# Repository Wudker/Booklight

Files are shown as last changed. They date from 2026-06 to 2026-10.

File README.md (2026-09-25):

# BookLight

Prototype

BookLight is a compact clip-on LED lamp designed for reading in low-light conditions. Its lightweight, print-in-place structure can be attached directly to a book cover or pages, providing local illumination without a larger desk lamp. The project combines a simple LED circuit with a custom 3D-printed clip and spring mechanism.

## Technologies

`LED lighting` `CAD` `3D printing` `Print-in-place design` `Mechanical prototyping`

## Usage and development status

Attach the clip to the book cover or a small group of pages and position the LED above the reading area. The current version is a functional prototype. Future improvements include a redesigned printed spring, a more ergonomic clip mechanism and a refined enclosure.

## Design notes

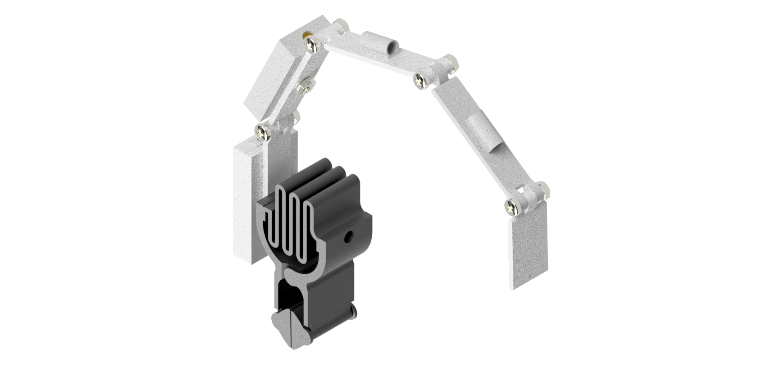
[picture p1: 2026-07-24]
Prototype/Hardware/Photo/booklight.png

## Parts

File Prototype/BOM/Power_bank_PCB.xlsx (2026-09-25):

Reference, | Qty | Value | Footprint | Link:
C1,C2,C24,C25,C26, | 5 | 100n | Capacitor_SMD:C_1206_3216Metric
C3,C4,C6,C7,C9,C21,C22,C23, | 8 | 22u | Capacitor_SMD:C_1206_3216Metric
C5,C12,C13,C30, | 4 | 0.1u | Capacitor_SMD:C_1206_3216Metric
C8,C10,C11,C14,C15,C16,C17,C18,C19,C20, | 10 | 10u | Capacitor_SMD:C_1206_3216Metric
C27, | 1 | 4.7u | Capacitor_SMD:C_1206_3216Metric
C28, | 1 | 1u | Capacitor_SMD:C_1206_3216Metric
C29, | 1 | 10n | Capacitor_SMD:C_1206_3216Metric
D1,D2, | 2 | LED | LED_SMD:LED_1206_3216Metric_Pad1.42x1.75mm_HandSolder
D3,D4, | 2 | SS32 | Diode_SMD:D_SMA
IC1,IC2, | 2 | TPS63070RNMR | KiCad:TPS630701RNMR
J1, | 1 | Alterative_charging | Connector_USB:USB_C_Receptacle_GCT_USB4125-xx-x-0190_6P_TopMnt_Horizontal
J2, | 1 | Vout | Connector_USB:USB_A_Molex_67643_Horizontal
L1,L2, | 2 | 1.5uH / XFL4020-152MEC | Inductor_SMD:L_Coilcraft_XAL4020-XXX
L3, | 1 | 1u / XEL5030-102 | Inductor_SMD:L_Coilcraft_XAL5030-XXX
Q1,Q3,Q4,Q5, | 4 | 2N7002 | Package_TO_SOT_SMD:SOT-23
Q2, | 1 | 8205A | Package_SO:TSSOP-8_4.4x3mm_P0.65mm
Q6, | 1 | DMP3099L | Package_TO_SOT_SMD:SOT-23
R1,R2,R17, | 3 | 1k | Resistor_SMD:R_1206_3216Metric
R3, | 1 | 680k | Resistor_SMD:R_1206_3216Metric
R4, | 1 | 130k | Resistor_SMD:R_1206_3216Metric
R5,R11,R14,R16,R22,R28,R29,R30, | 8 | 10k | Resistor_SMD:R_1206_3216Metric
R6, | 1 | 470k | Resistor_SMD:R_1206_3216Metric
R7, | 1 | 150k | Resistor_SMD:R_1206_3216Metric
R8,R10,R24, | 3 | 100k | Resistor_SMD:R_1206_3216Metric
R9, | 1 | 1.5k | Resistor_SMD:R_1206_3216Metric
R12, | 1 | 220k | Resistor_SMD:R_1206_3216Metric
R13, | 1 | 330k | Resistor_SMD:R_1206_3216Metric
R15, | 1 | 100 | Resistor_SMD:R_1206_3216Metric
R18,R21, | 2 | 5.1k | Resistor_SMD:R_1206_3216Metric
R19, | 1 | 22k | Resistor_SMD:R_1206_3216Metric
R20, | 1 | 33k | Resistor_SMD:R_1206_3216Metric
R23, | 1 | 732k | Resistor_SMD:R_1206_3216Metric
R25,R26,R27, | 3 | 4.7k | Resistor_SMD:R_1206_3216Metric
R31, | 1 | 0.05 | Resistor_SMD:R_1206_3216Metric
TP1, | 1 | Bat- | TestPoint:TestPoint_Pad_D2.0mm
TP2, | 1 | Vbat | TestPoint:TestPoint_Pad_D2.0mm
TP3, | 1 | Green_LED | TestPoint:TestPoint_Pad_D2.0mm
TP4, | 1 | Panel_power | TestPoint:TestPoint_Pad_D2.0mm
TP5, | 1 | Panel_gnd | TestPoint:TestPoint_Pad_D2.0mm
TP6, | 1 | Leds_common_GND | TestPoint:TestPoint_Pad_D2.0mm
TP7, | 1 | User_button- | TestPoint:TestPoint_Pad_D2.0mm
TP8, | 1 | SWDIO | TestPoint:TestPoint_Pad_D2.0mm
TP9, | 1 | SWCLK | TestPoint:TestPoint_Pad_D2.0mm
TP10, | 1 | Red_LED | TestPoint:TestPoint_Pad_D2.0mm
TP11, | 1 | Yellow_LED | TestPoint:TestPoint_Pad_D2.0mm
TP12, | 1 | User_button+ | TestPoint:TestPoint_Pad_D2.0mm
U1, | 1 | TP4056-42-ESOP8 | Package_SO:SOIC-8-1EP_3.9x4.9mm_P1.27mm_EP2.41x3.3mm_ThermalVias
U2, | 1 | MCP4018-10k | Package_TO_SOT_SMD:SOT-363_SC-70-6
U3, | 1 | DW01A | Package_TO_SOT_SMD:SOT-23-6
U4, | 1 | TPS61022 | Package_DFN_QFN:Texas_RWU0007A_VQFN-7_2x2mm_P0.5mm
U5, | 1 | STM32U031F8Px | Package_SO:TSSOP-20_4.4x6.5mm_P0.65mm
U6, | 1 | INA219AxD | Package_SO:SOIC-8_3.9x4.9mm_P1.27mm

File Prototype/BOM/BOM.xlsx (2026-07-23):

Name | Shop | Quantity
Cell | Botland_Lipol (https://botland.com.pl/akumulatory-li-pol-1s-37v/15598-akumulator-li-pol-akyga-250mah-1s-37v-zlacze-jst-bec-gniazdo-30x17x6mm-5904422324117.html) | 1
Charging module | Botland_TP4056 (https://botland.com.pl/ladowarki-elektryczne/16979-ladowarka-li-ion-hw-373-v121-tp4056-pojedyncza-cela-1s-37v-usb-typ-c-z-zabezpieczeniami-5904422326708.html) | 1
LED | Allegro_LED (https://allegro.pl/oferta/miniaturowa-lampka-usb-super-jasna-18122114240) | 1
Switch | Botland_switch (https://botland.com.pl/przelaczniki-suwakowe-i-przesuwne/5273-przelacznik-suwakowy-ss22t20-2-pozycyjny-5szt-5904422357030.html) | 1

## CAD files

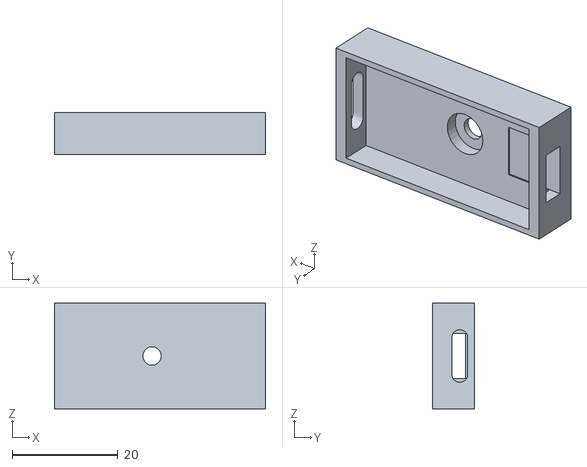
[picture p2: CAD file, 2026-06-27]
Prototype/Hardware/Parts/TP_box.stl
40.0 x 8.00 x 20.0

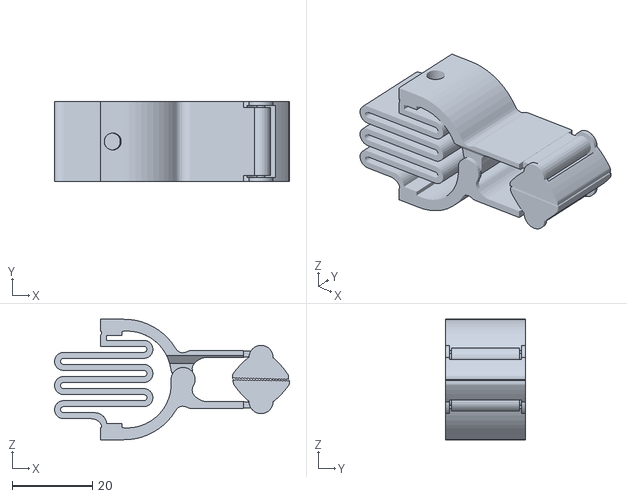
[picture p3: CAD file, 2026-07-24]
Prototype/Hardware/SLT/gripper.stl
58.5 x 20.0 x 30.0

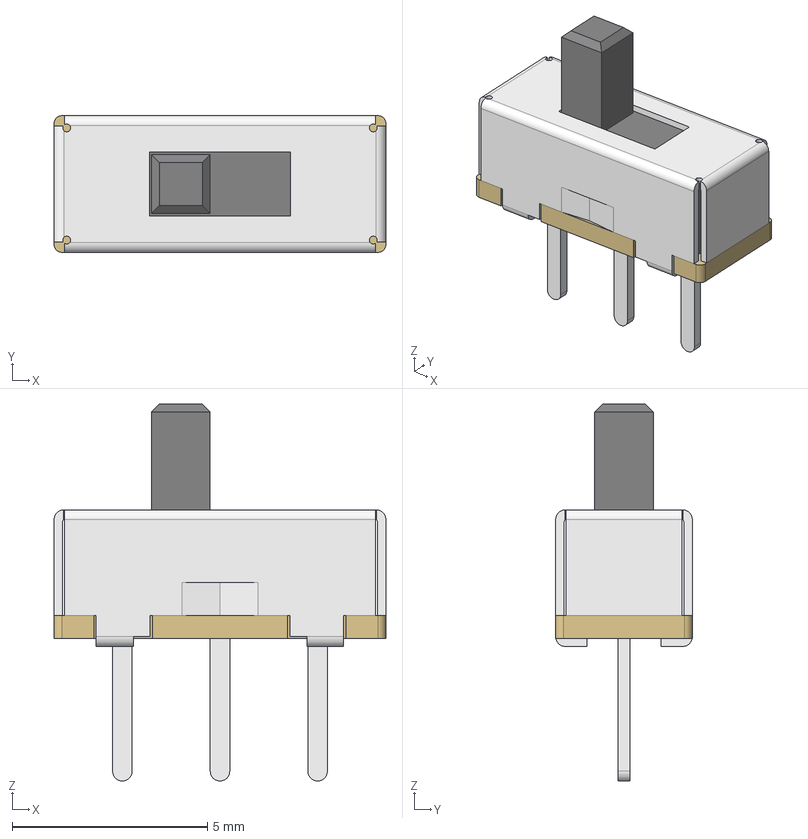
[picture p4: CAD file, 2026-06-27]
Prototype/Hardware/Parts/SPDT slide switch SS12D00.step
8.50 x 3.50 x 9.66 mm

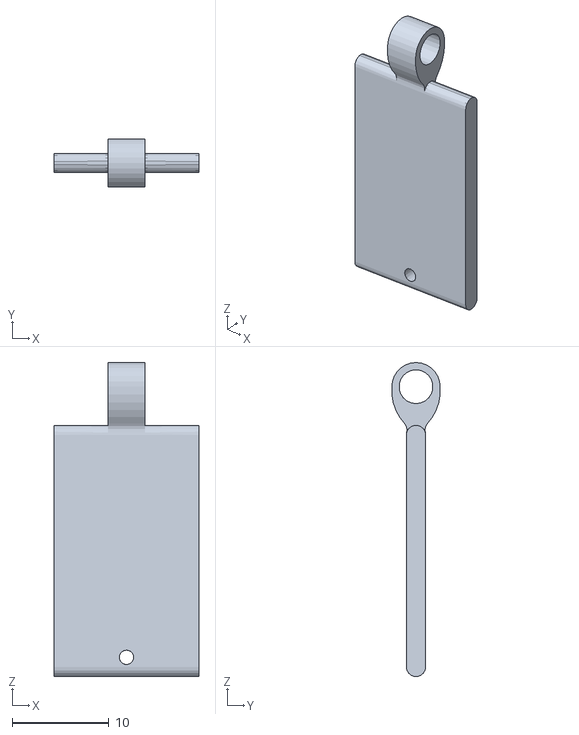
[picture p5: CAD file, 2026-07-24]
Prototype/Hardware/SLT/Arm_efector.stl
15.0 x 5.00 x 32.5

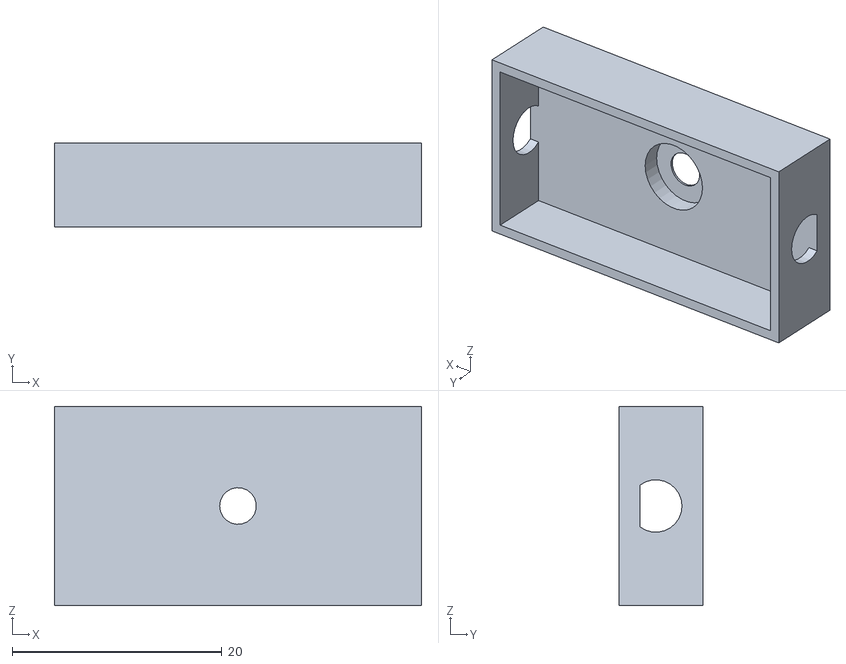
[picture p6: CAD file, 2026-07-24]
Prototype/Hardware/SLT/Battery_box.stl
35.0 x 8.00 x 19.0

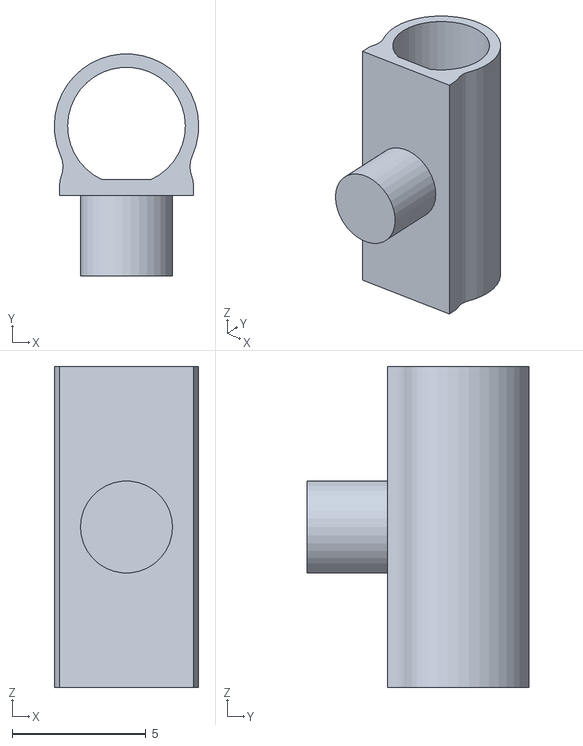
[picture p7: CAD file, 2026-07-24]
Prototype/Hardware/SLT/wire_loop.stl
5.40 x 8.29 x 12.0

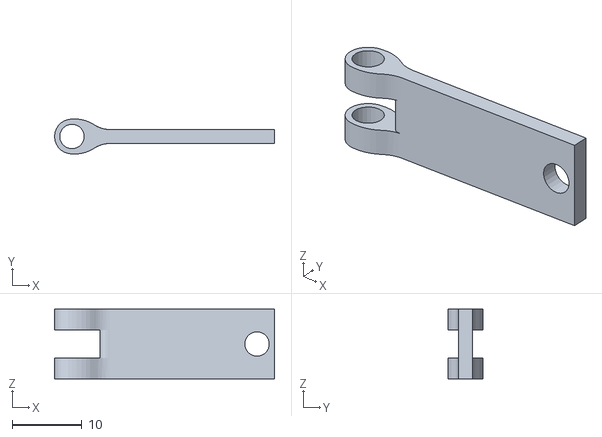
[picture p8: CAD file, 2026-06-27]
Prototype/Hardware/SLT/lamp_base.stl
31.5 x 5.02 x 10.0

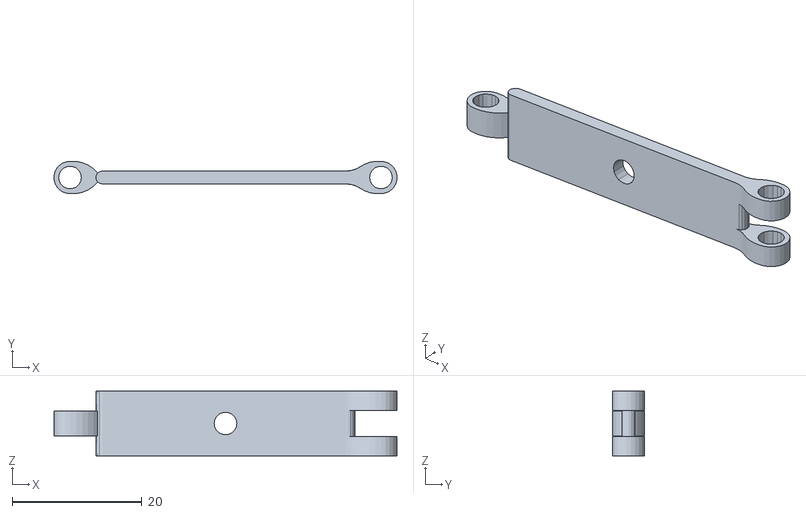
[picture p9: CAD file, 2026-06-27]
Prototype/Hardware/SLT/lamp_link.stl
52.9 x 5.00 x 10.0

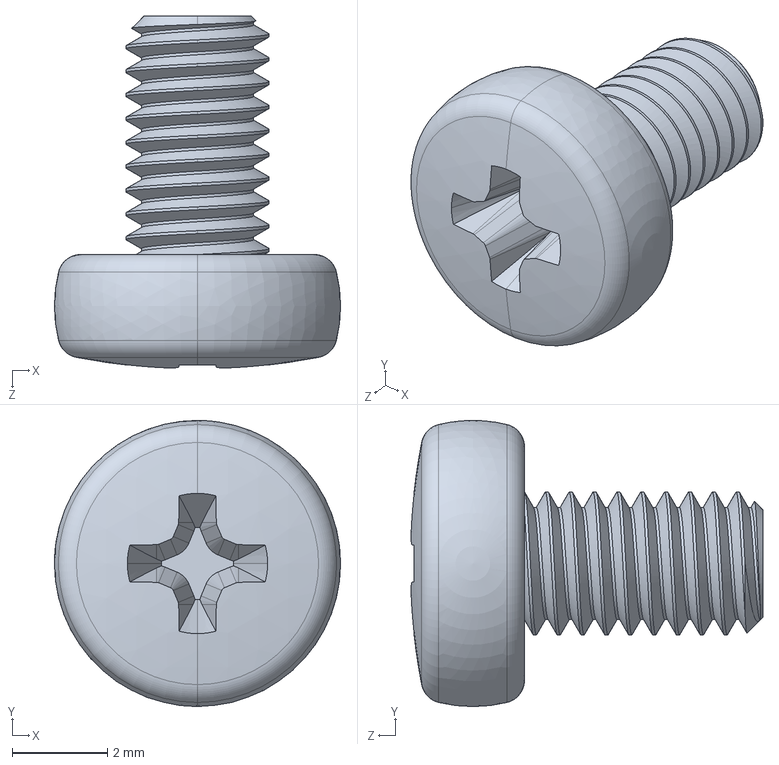
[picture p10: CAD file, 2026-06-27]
Prototype/Hardware/Parts/92005A114_Steel Pan Head Phillips Screw.STEP
6.00 x 6.00 x 7.38 mm

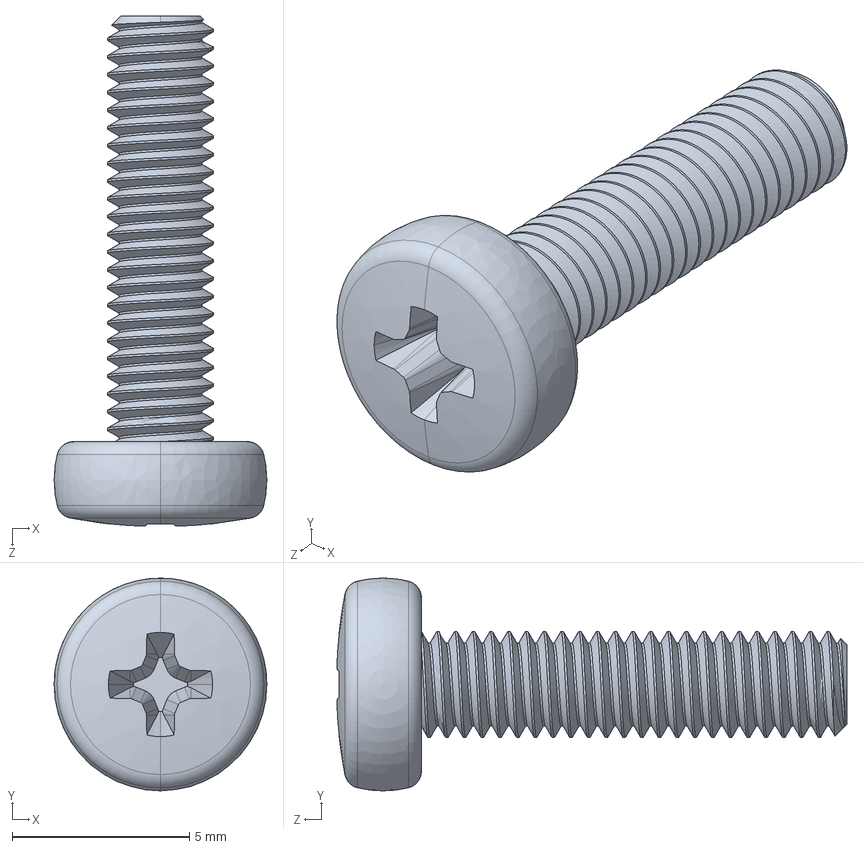
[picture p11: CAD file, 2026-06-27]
Prototype/Hardware/Parts/92005A122_Steel Pan Head Phillips Screw.STEP
6.00 x 6.00 x 14.4 mm

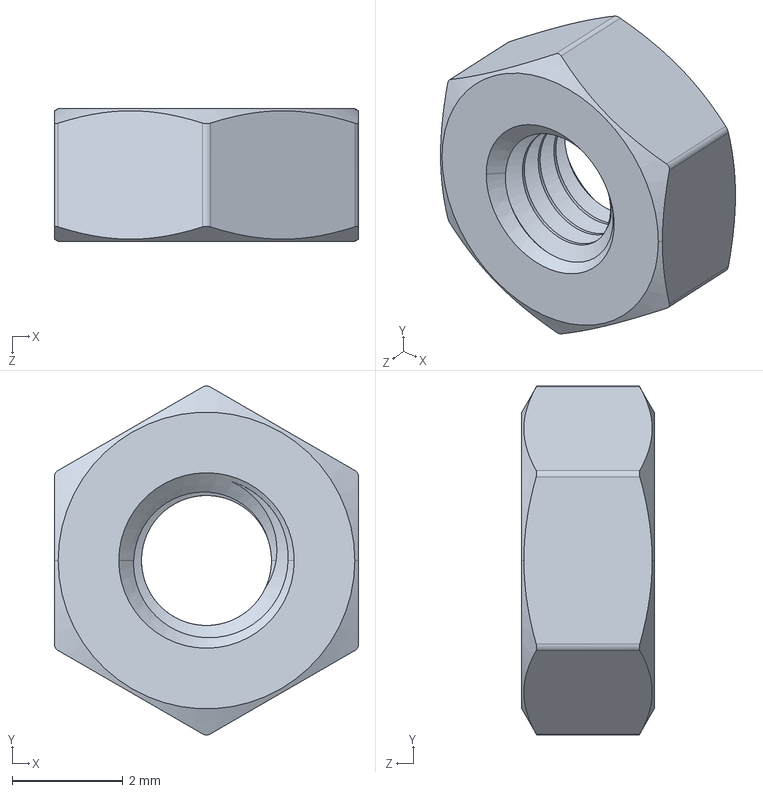
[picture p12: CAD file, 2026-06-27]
Prototype/Hardware/Parts/90591A250_Zinc-Plated Steel Hex Nut.STEP
5.50 x 6.31 x 2.40 mm

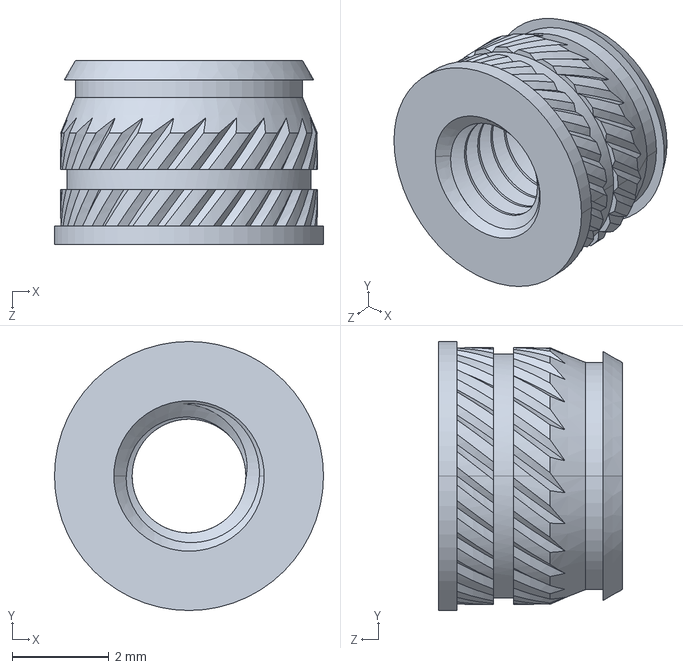
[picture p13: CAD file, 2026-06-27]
Prototype/Hardware/Parts/94180A331_Brass Tapered Heat-Set Inserts for Plastic.STEP
5.56 x 5.56 x 3.80 mm

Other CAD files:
Prototype/Hardware/SLT/Electronic_box.stl
Prototype/Hardware/OldVersions/main.0019.iam
Prototype/Hardware/Parts/90591A250_Zinc-Plated Steel Hex Nut/90591A250_Zinc-Plated Steel Hex Nut.ipt
Prototype/Hardware/Parts/92005A114_Steel Pan Head Phillips Screw/92005A114_Steel Pan Head Phillips Screw.ipt
Prototype/Hardware/Parts/92005A122_Steel Pan Head Phillips Screw/92005A122_Steel Pan Head Phillips Screw.ipt
Prototype/Hardware/Parts/94180A331_Brass Tapered Heat-Set Inserts for Plastic/94180A331_Brass Tapered Heat-Set Inserts for Plastic.ipt
Prototype/Hardware/Parts/Battery_box.ipt
Prototype/Hardware/Parts/Battery_prop.ipt
Prototype/Hardware/Parts/SPDT slide switch SS12D00/SPDT slide switch SS12D00.ipt
Prototype/Hardware/Parts/TP4056_Charging_Module_Type_C/TP4056_Charging_Module_Type_C.ipt
Prototype/Hardware/Parts/White - IR LED/White - IR LED.ipt
Prototype/Hardware/Parts/arm_1.ipt
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

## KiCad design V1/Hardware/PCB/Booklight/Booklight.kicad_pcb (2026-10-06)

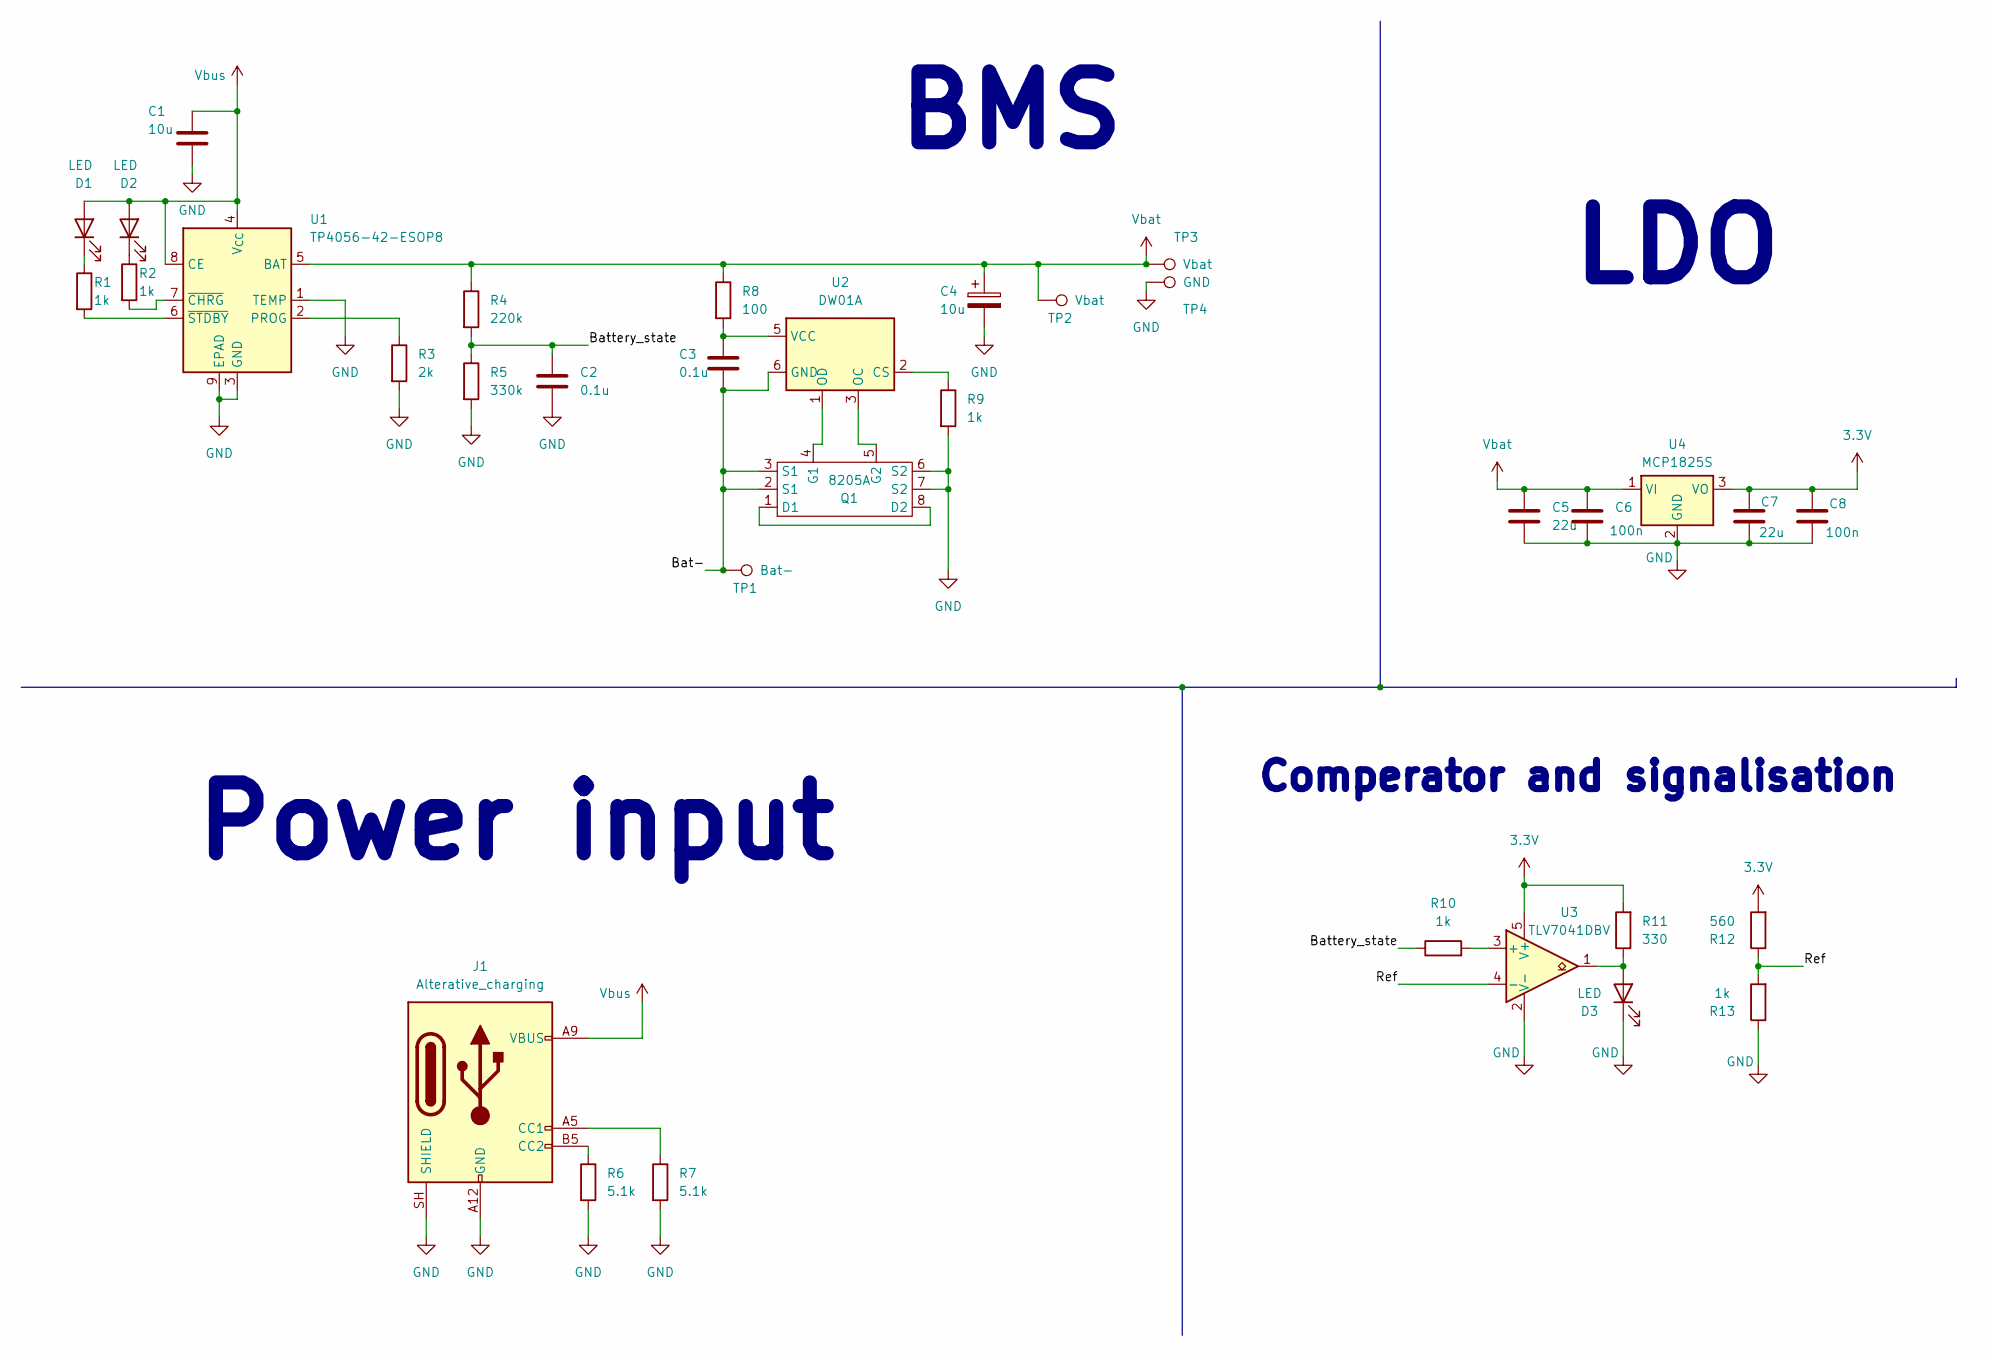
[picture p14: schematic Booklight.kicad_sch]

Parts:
C1, C4: 10u; C_1206_3216Metric
C2, C3: 0.1u; C_1206_3216Metric
C5, C7: 22u; C_1206_3216Metric
C6, C8: 100n; C_1206_3216Metric
D1, D2, D3: LED; LED_1206_3216Metric_Pad1.42x1.75mm_HandSolder
J1: Alterative_charging; USB_C_Receptacle_GCT_USB4125-xx-x-0190_6P_TopMnt_Horizontal
Q1: 8205A; TSSOP-8_4.4x3mm_P0.65mm
R1, R2, R9, R10, R13: 1k; R_1206_3216Metric
R3: 2k; R_1206_3216Metric
R4: 220k; R_1206_3216Metric
R5: 330k; R_1206_3216Metric
R6, R7: 5.1k; R_1206_3216Metric
R8: 100; R_1206_3216Metric
R11: 330; R_1206_3216Metric
R12: 560; R_1206_3216Metric
TP1: Bat-; TestPoint_Pad_D2.0mm
TP2, TP3: Vbat; TestPoint_Pad_D2.0mm
TP4: GND; TestPoint_Pad_D2.0mm
U1: TP4056-42-ESOP8; SOIC-8-1EP_3.9x4.9mm_P1.27mm_EP2.41x3.3mm_ThermalVias
U2: DW01A; SOT-23-6
U3: TLV7041DBV; SOT-23-5
U4: MCP1825S; SOT-223-3_TabPin2

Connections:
3.3V: C7.1, C8.1, R11.2, R12.2, U3.5 (V+), U4.3 (VO)
/Bat-: C3.1, Q1.2 (S1), Q1.3 (S1), TP1.1 (1_1), U2.6 (GND)
/Battery_state: C2.1, R4.2, R5.1, R10.1
/Ref: R12.1, R13.2, U3.4 (-)
GND: C1.2, C2.2, C4.2, C5.2, C6.2, C7.2, C8.2, D3.1 (K), J1.A12 (GND), J1.B12 (GND), J1.SH (SHIELD), Q1.6 (S2), Q1.7 (S2), R3.2, R5.2, R6.2, R7.2, R9.2, R13.1, TP4.1 (1_1), U1.1 (TEMP), U1.3 (GND), U1.9 (EPAD), U3.2 (V-), U4.2 (GND)
unnamed: D1.1 (K), R1.1
unnamed: D2.1 (K), R2.1
unnamed: D3.2 (A), R11.1, U3.1
unnamed: J1.A5 (CC1), R7.1
unnamed: J1.B5 (CC2), R6.1
unnamed: Q1.1 (D1), Q1.8 (D2)
unnamed: Q1.4 (G1), U2.1 (OD)
unnamed: Q1.5 (G2), U2.3 (OC)
unnamed: R3.1, U1.2 (PROG)
unnamed: R2.2, U1.7 (~CHRG)
unnamed: R1.2, U1.6 (~STDBY)
unnamed: R9.1, U2.2 (CS)
unnamed: C3.2, R8.2, U2.5 (VCC)
unnamed: R10.2, U3.3 (+)
Vbat: C4.1, C5.1, C6.1, R4.1, R8.1, TP2.1 (1_1), TP3.1 (1_1), U1.5 (BAT), U4.1 (VI)
Vbus: C1.1, D1.2 (A), D2.2 (A), J1.A9 (VBUS), J1.B9 (VBUS), U1.4 (V_{CC}), U1.8 (CE)

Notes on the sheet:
LDO
BMS
Power input
Comperator and signalisation

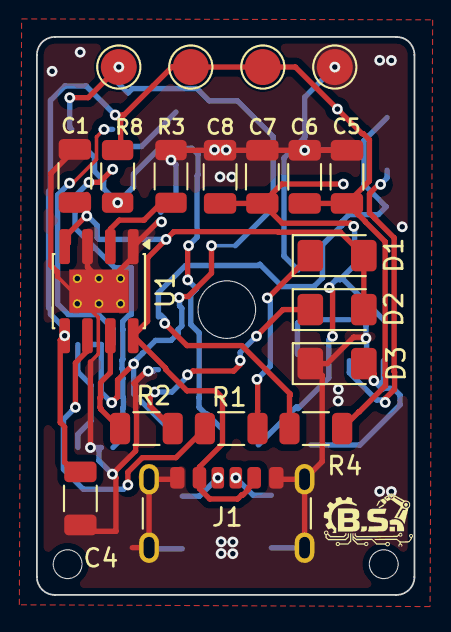
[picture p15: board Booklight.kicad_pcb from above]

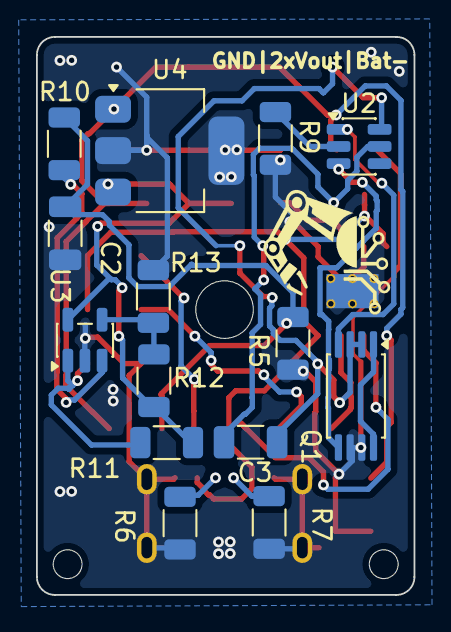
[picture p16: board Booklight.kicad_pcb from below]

Board: 2 copper layers, 21.0 x 31.0 mm, 34 parts (14 on the bottom side), 21 nets.

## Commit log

2026-06-27 Update prototype hardware parts and assembly
    Add new STL parts (Battery_box, TP_box, lamp_head, lamp_starter, main_clip) and archive an older assembly version (OldVersions/main.0015.iam). Update lamp_link.stl and Prototype/Hardware/main.iam to 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
    [Battery_box.stl, TP_box.stl, Zespół1.stl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]
2026-07-05 Clean up old hardware design versions
    Remove outdated version files from the hardware prototype OldVersions directories. Updated grab.ipt and spring.ipt parts.
    [arm_1.0007.ipt, arm_2.0008.ipt, elektronika.0003.ipt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]
2026-07-23 New concept implementation
    [BOM.xlsx, Battery_box.ipt, elektronika.ipt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]
2026-07-24 End phase prototype file cleaning
    [Arm_efector.stl, Battery_box.ipt, Battery_box.stl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]
2026-07-24 Add prototype hardware photos
    Add JPG and PNG photographs of the Booklight hardware prototype for documentation and reference.
2026-09-25 Initial commit of PCB
    [Booklight.kicad_pcb, Booklight.kicad_sch, Power_bank_PCB.xlsx]
2026-10-05 Swapped comperator
    [Booklight.kicad_pcb, Booklight.kicad_sch]
2026-10-05 Mid-work backup
    I believe some minor improvements can be made to the bottom layer of the PCB
    [Booklight.kicad_pcb]
2026-10-06 Add 3.3V regulator to PCB
    This change adds an MCP1825S LDO footprint and routes the 3.3V rail through the updated power network. It also updates board copper, via placement, net assignments, and KiCad metadata/UUIDs to match 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
    [Booklight.kicad_pcb]
